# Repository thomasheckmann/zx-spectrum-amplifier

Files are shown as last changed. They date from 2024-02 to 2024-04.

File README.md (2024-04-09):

# zx-spectrum-amplifier
DIY Amplifier from danish magazine for ZX Spectrum re-created in KiCad as close as possible to original design. This constructions was published in Ny Elektronik issue 3 in 1984.

# Original construction
This is the constructions as published in the magazine in 1984.
<table>
  <tr>
    <td colspan="3" align="center"></td>
  </tr>
  <tr>
    <td align="center"></td>
    <td align="center"></td>
    <td align="center"> </td>
  </tr>
  <tr>
    <td align="center">Schema</td>
    <td align="center">PCB</td>
    <td align="center">Components layout</td>
  </tr>
</table>

# Recreated construction

## First prototype
The main goal was to get the schema redrawn in KiCad and a first try at a PCB, in order to build a version to check if everything works.

| Schema | KiCad | PCB |
| --- | ----- | --- |
|||

First version of PBC was done by manually layout of tracks, according to the original component layouts from the magazine

## Second prototype
As the first version worked perfektly, the main goal was to add relevant plugs for EAR and DC power and resize the board to fit in a suitable enclosure. I even had to create a new footprint for the DC plug, but than again - great learning. Also a small trimmer-pot has been added, in order to be able to recude the noise that is generated in general - it can be skipped and replaced with a small wire, if you wish.

| KiCad  | PCB |
| --- | --- |
||

For the track layout, I decided to go with the autoroute plugin - as it makes a nice layout and makes a double sidded print as well.

The new PCB is adjusted to fit in a box of size 84mm X 56mm X 20mm. For example this enclosure box from [Hammond](https://www.hammfg.com/part/1591XXMGY)

## Final version (for now)
And this is how the final product turned out, fitting nicely in a standard enclosure.
| Enclosure | Assembled | In use |
| --- | --- | --- |
|||

## BOM
You will need the following componets:
* R1 - 10 Ohm 1/4W
* P1 - 4,7 kOhm Potentiometer, logarithmic mono
* C1 - 4,7 nF - ceramic
* C2 - 22 uF/16V - electrolytic
* C3 - 22 uF/16V - electrolytic
* C4 100 uF/16V - electrolytic
* C5 0,1 uF/35V tantalum
* IC1 - LM386N
* Trimmer Top Adjust P5/10 50K (Optional)
* Speaker 8 Ohm, pin headers, DC and Minijack plugs

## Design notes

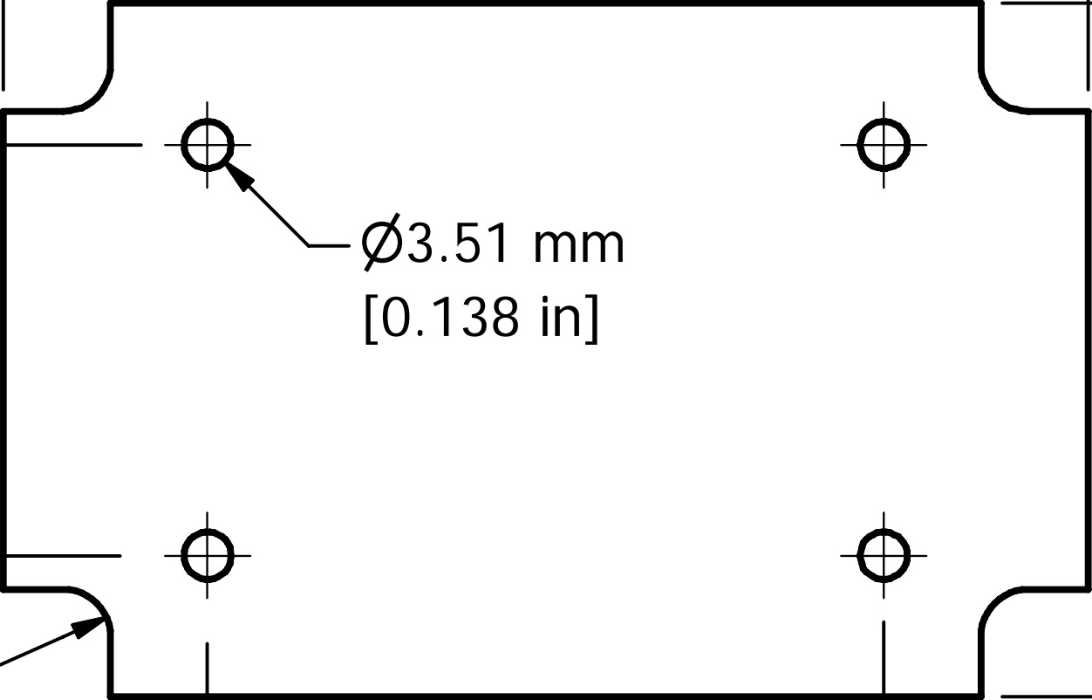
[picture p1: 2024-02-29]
board_layout_for_case.jpg

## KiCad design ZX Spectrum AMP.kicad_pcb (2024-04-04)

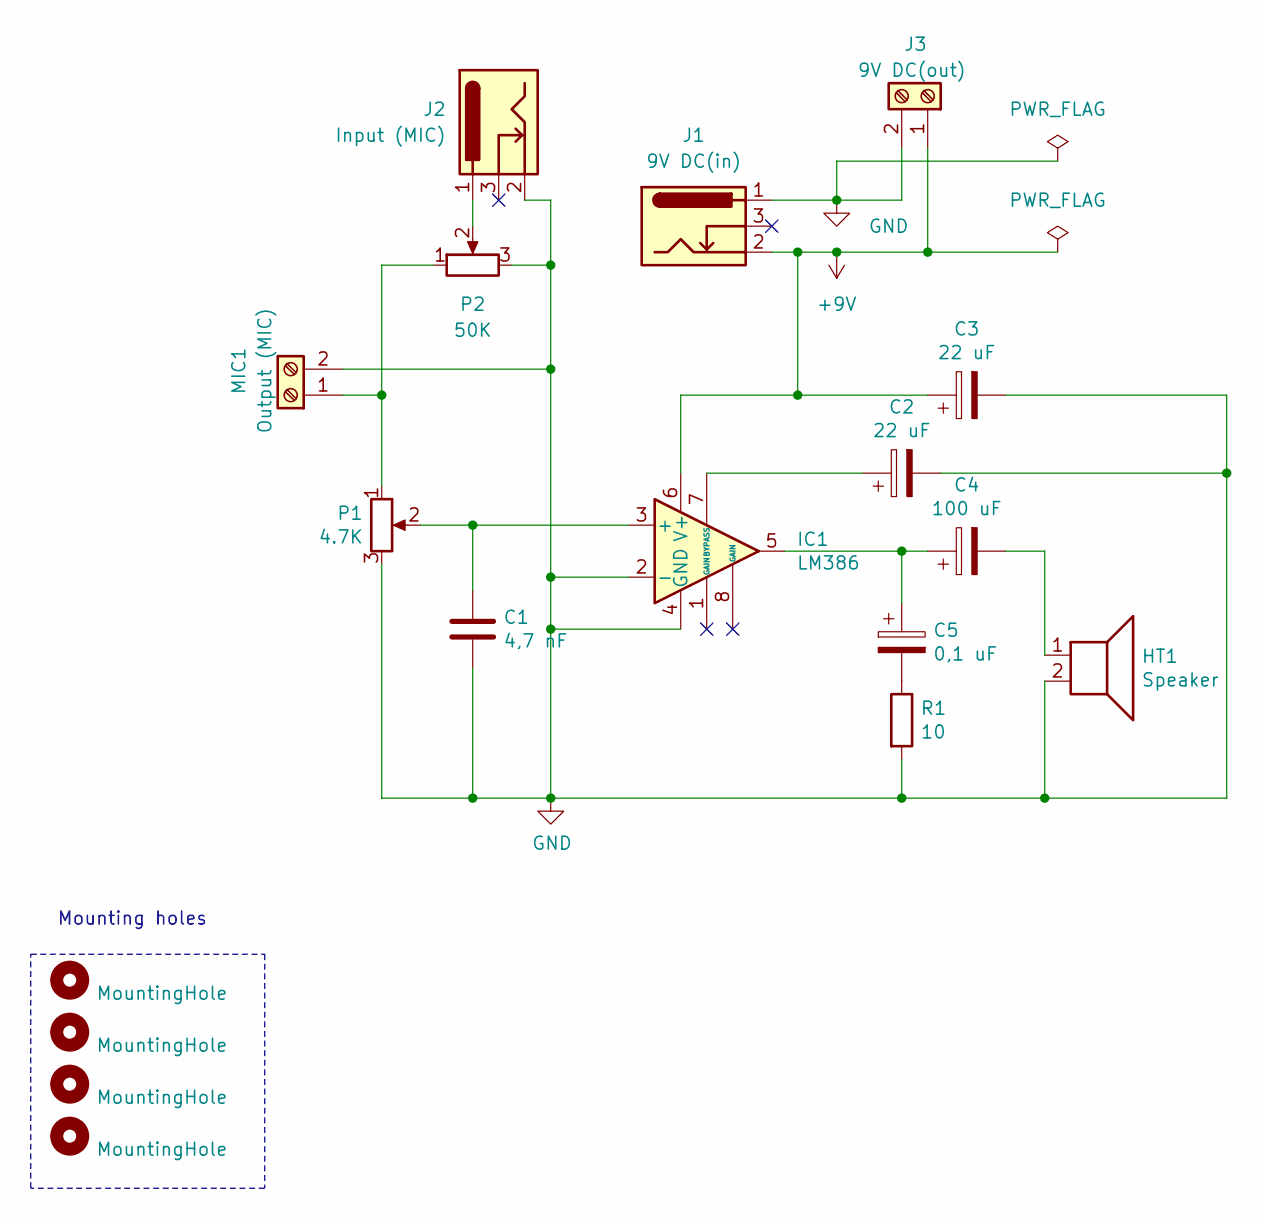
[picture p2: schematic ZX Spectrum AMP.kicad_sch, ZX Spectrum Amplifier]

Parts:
C1: 4,7 nF; C_Disc_D7.5mm_W5.0mm_P7.50mm
C2, C3: 22 uF; CP_Radial_D5.0mm_P2.50mm
C4: 100 uF; CP_Radial_D5.0mm_P2.50mm
C5: 0,1 uF; CP_Radial_Tantal_D4.5mm_P2.50mm
H1, H2, H3, H4: MountingHole; MountingHole_3.5mm
HT1: Speaker; PinHeader_1x02_P2.54mm_Horizontal
IC1: LM386; DIP-8_W7.62mm
J1: 9V DC(in); BarrelJack_GCT_DCJ200-10-A_Horizontal
J2: Input (MIC); 3.5mm mono jack chassis with switch
J3: 9V DC(out); PinHeader_1x02_P2.54mm_Horizontal
MIC1: Output (MIC); PinHeader_1x02_P2.54mm_Horizontal
P1: 4.7K; Potentionmeter
P2: 50K; Potentiometer_Piher_PT-10-V10_Vertical
R1: 10; R_Axial_DIN0207_L6.3mm_D2.5mm_P10.16mm_Horizontal

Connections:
+9V: C3.1, IC1.6 (V+), J1.2, J3.1
GND: C1.2, C2.2, C3.2, HT1.2, IC1.2 (-), IC1.4 (GND), J1.1, J2.2, J3.2, MIC1.2, P1.3, P2.3, R1.2
unnamed: C4.1, C5.1, IC1.5
unnamed: C4.2, HT1.1
unnamed: C5.2, R1.1
unnamed: C1.1, IC1.3 (+), P1.2
unnamed: C2.1, IC1.7 (BYPASS)
unnamed: J2.1, P2.2
unnamed: MIC1.1, P1.1, P2.1

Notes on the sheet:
Mounting holes

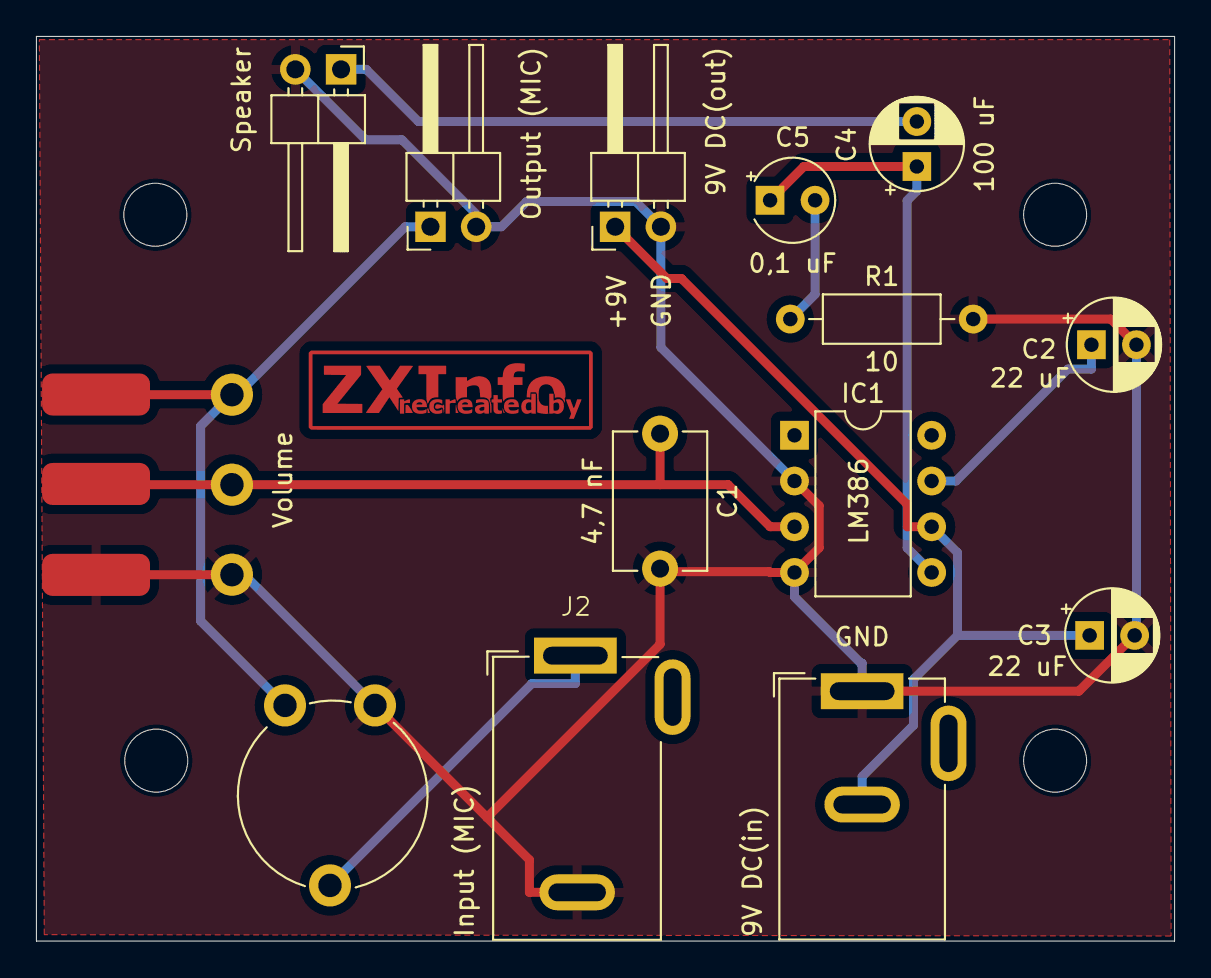
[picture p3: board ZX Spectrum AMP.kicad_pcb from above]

Board: 2 copper layers, 63.2 x 50.3 mm, 19 parts (0 on the bottom side), 9 nets.

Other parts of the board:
G200: LOGO; ZXInfo_kicad_logo_copper_16.5x5

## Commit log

2024-02-29 Gerber for V2 sendt to production
    [ZX Spectrum AMP-B_Cu.gbr, ZX Spectrum AMP-B_Mask.gbr, ZX Spectrum AMP-B_Paste.gbr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]
2024-04-02 v0.3 - add logo + corrected text
    [ZX Spectrum AMP.kicad_pcb, ZX Spectrum AMP.kicad_sch]
2024-04-04 Final v3 - gerber
    [ZX Spectrum AMP-B_Cu.gbr, ZX Spectrum AMP-B_Mask.gbr, ZX Spectrum AMP-B_Paste.gbr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]
